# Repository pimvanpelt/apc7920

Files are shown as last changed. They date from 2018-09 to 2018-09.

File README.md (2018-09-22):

# APC7920 based on ESP32

This is a project that replaces the older and unmaintained microcontroller
units in APC's famous rack PDU, the AP7920.

## Intro to AP7920

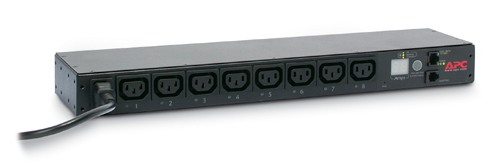
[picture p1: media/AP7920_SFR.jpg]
image of AP7920


The AP7920 is an 8-port switchable rack mounted power distribution unit. It
features three main components:

1.  A power supply board, which has two 24V power supplies (PSU1 and PSU2) and
    three current sensors (Phase A, B and C). Each current sensor measures
    current from 0..30A AC. When sold in Europe, only one of these is used
    (Phase B).
1.  A microcontroller, based on an older Atmel chip, which features serial
    via an RJ12 plug, and 10/100 Ethernet via an RJ45 plug, and a 7-segment
    display which shows load on Phase B.
1.  A relay board, which features a general purpose I2C GPIO expander based on
    PCF8574, and eight 24V relays, one for each port on the front.

The design of this PDU is rather well done, with two power supplies, and a 
decoupled control plane. The wiring is of high quality, even after many
years of service the components are still in pristine shape. Shrink wrap
is used on the wiring for extra safety and the solder quality is very high.

If the microcontroller reboots or fails, the I2C GPIO expander stays put.
This allows operators to upgrade/reboot/tinker-with the management board
without interrupting service to the load.

### Pinouts

#### Power Supply Board

The power supply board has a 10-pin 2mm pitch connector. It exposes the two
24V power supplies, each with their own ground, and the three current sensors,
with their own separate common ground.

The black wire on the ribbon cables is Pin1. 

Pin | Meaning | Pin | Meaning
--- | --- | --- | ---
1 | I-Sens Phase C | 2 | I-Sens GND
3 | I-Sens Phase A | 4 | I-Sens GND
5 | +24V PSU1 | 6 | +24V PSU1
7 | I-Sens Phase B | 8 | GND PSU1
9 | GND PSU2 | 10 | +24V PSU2

It's worth pointing out that on the power supply board, all ground planes
are separated (so there's one ground pin for PSU1, one for PSU2 and one for
the current sensors).

#### Relay Board

The relay board has a 10-pin 2mm pitch connector. It exposes the I2C chip
which takes common `SDA`, `SDL`, `3.3V` and `GND` pins, and exposes three
address pins `ADDR0`, `ADDR1`, and `ADDR2`. This is presumably done so that
the microcontroller can address up to 8 of these relay boards. It also takes
24V in, which is used to drive the relays.

Pin | Meaning | Pin | Meaning
--- | --- | --- | ---
1 | GND | 2 | GND
3 | VDD (3.3V) | 4 | SDA
5 | +24V | 6 | +24V
7 | ADDR0 | 8 | SDL
9 | ADDR1 | 10 | ADDR2

AP7920 only has one expander, so it doesn't really matter which address
the MCU selects.

## Interposer board

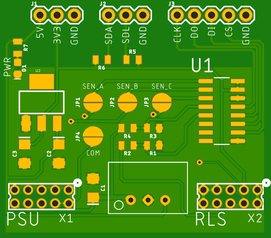
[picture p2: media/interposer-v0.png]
Eagle Interposer


This project works by replacing the two ribbon cables that go from the power
supply board and the relay board to the microcontroller. It's designed to
be a plugin replacement -- just remove the connectors from the microcontroller
and plug them into the interposer board instead.

The interposer has a few components. Firstly, there's a DC/DC buck converter
which takes 24V from PSU1 and switches it down to 5V. Then, there's a LDO that
takes the 5V and regulates it down to 3.3V. Lastly, there's an ADC chip that
measures the current on Phase A,B,C and the voltage out of PSU1 and PSU2 by 
using voltage dividers (the ADC runs at 3.3V so at least a 7:1 divider is
necessary to measure the 24V coming out of the PSUs). The 24V rail from PSU2
is looped through to the relay board. It exposes its 3.3V rail to the relay
board as well, to power the GPIO expander and a few other components there.

It exposes its ADC chip on the SPI header (taking `CS`, `CLK`, `DI` and `DO`)
and it exposes the GPIO expander from the relay board on the I2C header
(showing `SDA`, `SDL`). It offers the 5V and 3.3V rails on the PWR header.
This is enough to connect any other microcontroller that speaks I2C and SPI
instead of the microcontroller that comes with the AP7920 itself. The
interposer assumes only one PCF8574 chip, so it ties all three address pins
`ADDR0`, `ADDR1` and `ADDR2` to `GND`.

The interposer also ties `GND` together from both PSUs, as the original
microcontroller also does that. It has a solder pad (J4) that allows the
current sensor ground to be tied to the main ground as well. In production,
all four solder pads (J1..J4) should be soldered closed. This connects the
current sensor output to the ADC. You can measure the voltage between J4
and J1..J3 to see the current sensed on Phase A..C.

**NOTE** - There is a design flaw in the PCB as it assumes the current
sensor common should be tied to ground, which is not the case. It should be
tied to `VCC/2` so that the signal of the current transformer outputs hovers
between 0-3.3V instead of -1.65-1.65V. A new version is upcoming :)

### BOM

The following components are readily available on Mouser and Digikey. The
full bill of materials for the interposer is as such:

*   R1,R3: 10K Ohm -- voltage divider
*   R2,R4: 75K Ohm -- voltage divider (7:1 minimum)
*   R5,R6: 10K Ohm -- pullup for I2C, optional
*   R7: 220 Ohm -- for blue LED
*   D1: Blue LED 
*   C1: 22uF Tantalum 35V
*   C2,C3: 10uF Tantalum 16V
*   U1: MCP3208 -- 150mil SOIC (Microchip)
*   U2: TSR1-2450 (Traco Power)
*   X1, X2: 5x2 pin 2mm spaced header
*   J1, J2: 3x1 pin 2.54mm spaced header
*   J3: 5x1 pin 2.54mm spaced header

## ESP32 / ESP8266

There are two chips we have to interface with:

*   MCP3208 [datasheet](media/MCP3208.pdf); [driver](https://github.com/mongoose-os-libs/mcp320x-spi)
*   PCF8574 [datasheet](media/PCF8574.pdf); [driver](https://github.com/mongoose-os-libs/pcf8574-i2c)

Libraries for these two chips are readily available for Arduino, but I've
ported them as well to [Mongoose OS](https://mongoose-os.com/) which is my
development platform of choice. This makes writing the program really easy.

### Source Code

See the [firmware](firmware/README.md) directory for information on the firmware.

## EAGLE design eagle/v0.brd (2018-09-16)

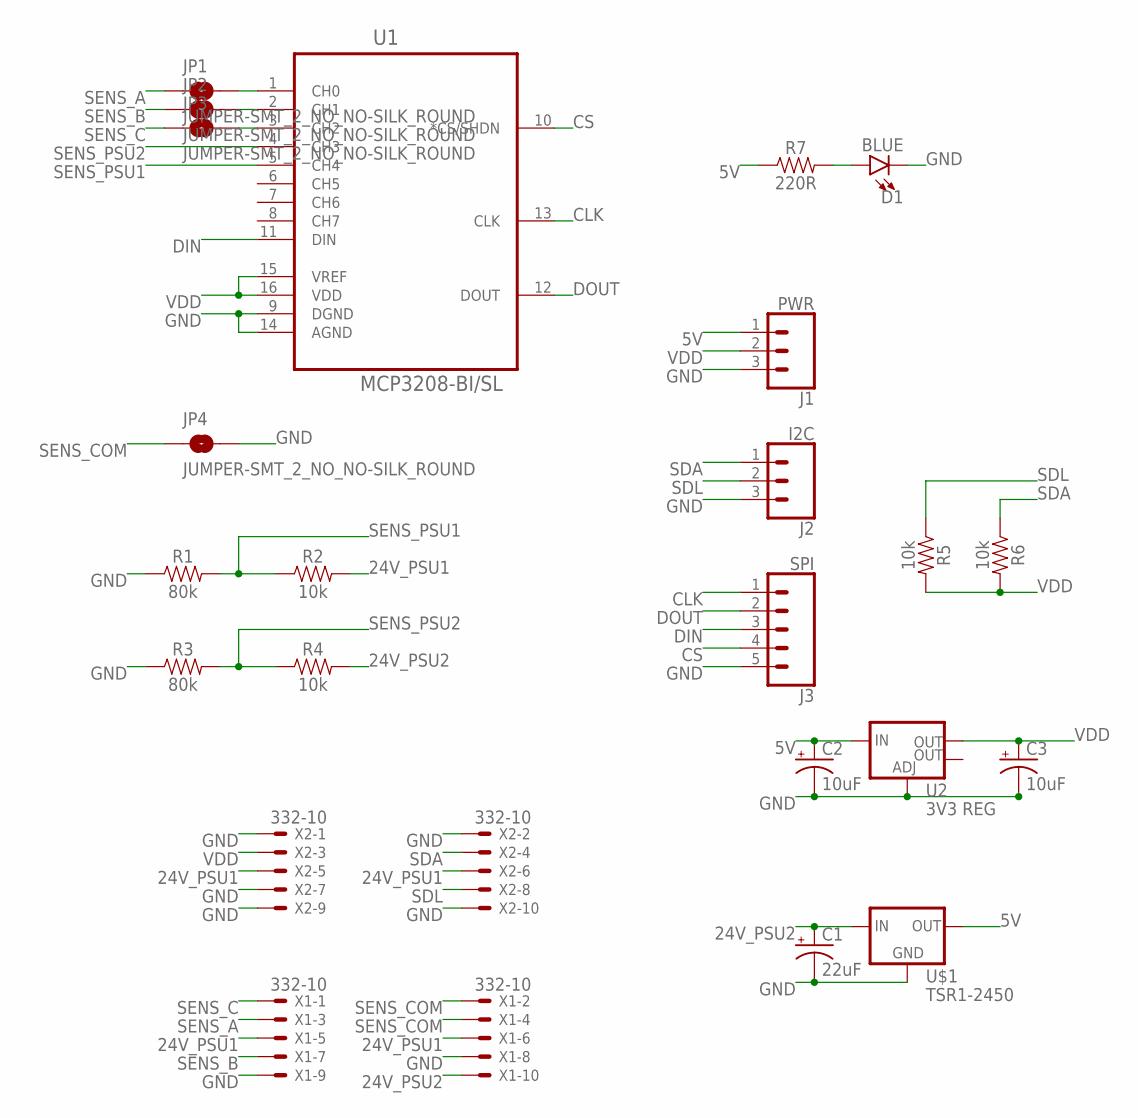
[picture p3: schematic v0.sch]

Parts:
C1: 22uF; EIA3216
C2, C3: 10uF; EIA3216
D1: BLUE; LED-0603
J1: PWR; 1X03
J2: I2C; 1X03
J3: SPI; 1X05
JP1, JP2, JP3, JP4: JUMPER-SMT_2_NO_NO-SILK_ROUND; SMT-JUMPER_2_NO_NO-SILK_ROUND
R1, R3: 80k; 0805
R2, R4, R5, R6: 10k; 0805
R7: 220R; 0805
U1: MCP3208-BI/SL; SOIC127P600X175-16N
U2: 3V3 REG; SOT223
U$1: TSR1-2450
X1, X2: 332-10

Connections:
5V: C2.+, J1.1, R7.1, U2.3 (IN), U$1.3 (OUT)
24V_PSU1: R2.2, X1.5, X1.6, X2.5, X2.6
24V_PSU2: C1.+, R4.2, U$1.1 (IN), X1.10
CLK: J3.1, U1.13 (CLK)
CS: J3.4, U1.10 (*CS/SHDN)
DIN: J3.3, U1.11 (DIN)
DOUT: J3.2, U1.12 (DOUT)
GND: C1.-, C2.-, C3.-, D1.C, J1.3, J2.3, J3.5, JP4.2, R1.1, R3.1, U1.9 (DGND), U1.14 (AGND), U2.1 (ADJ), U$1.2 (GND), X1.8, X1.9, X2.1, X2.2, X2.7, X2.9, X2.10
unnamed: JP1.2, U1.1 (CH0)
unnamed: JP2.2, U1.2 (CH1)
unnamed: JP3.2, U1.3 (CH2)
unnamed: D1.A, R7.2
SDA: J2.1, R6.1, X2.4
SDL: J2.2, R5.1, X2.8
SENS_A: JP1.1, X1.3
SENS_B: JP2.1, X1.7
SENS_C: JP3.1, X1.1
SENS_COM: JP4.1, X1.2, X1.4
SENS_PSU1: R1.2, R2.1, U1.5 (CH4)
SENS_PSU2: R3.2, R4.1, U1.4 (CH3)
VDD: C3.+, J1.2, R5.2, R6.2, U1.15 (VREF), U1.16 (VDD), U2.2 (OUT), X2.3

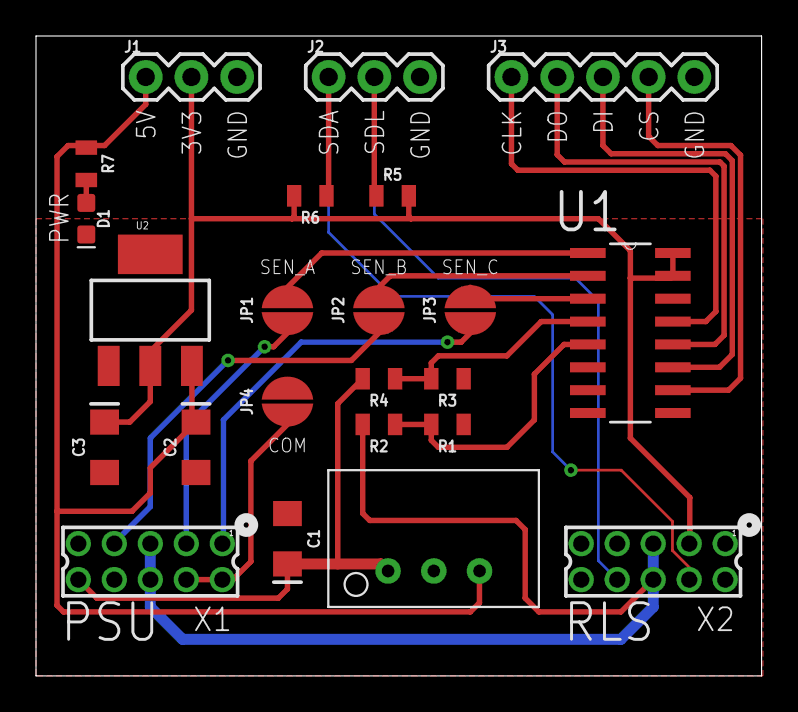
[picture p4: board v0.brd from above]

Board: 2 copper layers, 40.3 x 35.5 mm, 23 parts (0 on the bottom side), 21 nets.

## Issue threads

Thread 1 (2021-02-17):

Sense ground change.

camprr, 2021-02-17:
Pim,

interested in looking at this as I have a broken apc7920. Did you manage to make the modification needed to the PCB to sense the voltage correctly as you state in the Readme? Thanks for _any_ response.

Robert

pimvanpelt, 2021-02-17:
Hoi Robert, thanks for reaching out. The interposer board posted does work
but I did not pursue the project further. It turns out the ESP32 ADC cannot
sample as fast as I was lead to believe when reading its I2S peripheral
documentation, and then the project fell by the wayside.

On Wed, Feb 17, 2021 at 9:55 PM Robert Campbell <notifications@github.com>
wrote:

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

--
Pim van Pelt <pim@ipng.nl>
PBVP1-RIPE - http://www.ipng.nl/

camprr, 2021-02-22:
Good to know, thanks for getting back to me on that!
Maybe I'll 'just' make the switching work then. Have a broken 7920 here that I'd like to get working again. Otherwise is would just be a simple 'hotwire' from the jumper to the pin you mention, right?

pimvanpelt, 2021-02-22:
Making the switching part works is trivial - there's an I2C speaking 8574
GPIO expander on the relay board which has all of its pins (address and
clock / data) exposed on the header. This chip speaks 3.3V and drives the
relays.
I wrote a driver for it here:
https://github.com/mongoose-os-libs/pcf857x-i2c

You can connect your I2C master directly to those SDL/SDA pins and tie
ADDR0,ADDR1,ADDR2 to ground (or any other combination), and then switch the
relays by writing a byte to the latch.
All up, the Mongoose OS code should be possible with less than 100 lines of
code this way.

On Mon, Feb 22, 2021 at 10:06 AM Robert Campbell <notifications@github.com>
wrote:

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

--
Pim van Pelt <pim@ipng.nl>
PBVP1-RIPE - http://www.ipng.nl/

DanMan32, 2023-06-29:
I too came across this project, looking for a way to revive an ap7932  which is a 24P 120V 30A managed PDU.
The processor board just failed yesterday which is a board piggybacked to the display/interface board.
I suspect the buck converter on the processor board failed, one of the tiny chips near the capacitors/inductor gets rather hot.
I was hating to have to dispose of the PDU just because of the processor board having failed.  I figured there was some sort of controlling interface to the relay/outlet boards, your information provided a lot of what I would need to be able to control the outlets.
Any idea what the designation of header pins between the processor board and display/interface board might be?

I hope the I2C and address selector lines from the relay boards go directly to the header pins to the processor board, that would make interfacing with the relay boards from a microcontroller SO much easier than having to source those tiny ribbon cable headers.

DanMan32, 2023-06-29:
Since you're using an external ADC, I'm surprised you have issues interfacing with the ESP32 to read the current.
Or was that comment about the ESP32 sample rate being too slow before you added the ADC IC?

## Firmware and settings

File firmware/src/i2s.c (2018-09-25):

#include "mgos.h"
#include "mgos_config.h"
#include "mgos_prometheus_metrics.h"
#include "driver/i2s.h"
#include "soc/syscon_reg.h"
#include "esp_event_loop.h"
#include "driver/adc.h"

#define SAMPLE_RATE     (9000)
#define I2S_NUM         (0)
#define RINGBUF_SIZE    (16)

struct i2s_scanner_adc_channel {
  uint32_t sum;
  uint16_t count;
  uint16_t min;
  uint16_t max;
};

struct i2s_scanner_adc_channel_set {
  struct i2s_scanner_adc_channel chan[8];
};

struct i2s_scanner_adc_channel_ringbuf {
  struct i2s_scanner_adc_channel_set channel_set[RINGBUF_SIZE];
  uint8_t                            head;
};

struct i2s_scanner_stats {
  uint32_t read_usecs;
  uint32_t read_bytes;
  uint32_t read_count;
};

static QueueHandle_t s_i2s_event_queue;

static struct i2s_scanner_stats s_stats;
static struct i2s_scanner_adc_channel_ringbuf s_ringbuf;
static struct mg_connection *s_udp_nc = NULL;

static void prometheus_metrics_fn(struct mg_connection *nc, void *user_data) {
  struct i2s_scanner_adc_channel_set *channel_set = &s_ringbuf.channel_set[s_ringbuf.head];

  mgos_prometheus_metrics_printf(nc, COUNTER, "i2s_scanner_read_count", "Total samples from I2S",
                                 "%u", s_stats.read_count);
  mgos_prometheus_metrics_printf(nc, COUNTER, "i2s_scanner_read_bytes_total", "Total bytes from I2S",
                                 "%u", s_stats.read_bytes);
  mgos_prometheus_metrics_printf(nc, COUNTER, "i2s_scanner_read_usecs_total", "Total time spent in I2S in microseconds",
                                 "%u", s_stats.read_usecs);

  for (int i = 0; i < 8; i++) {
    mgos_prometheus_metrics_printf(nc, GAUGE, "i2s_scanner_raw", "Raw data from I2S Scanner",
                                   "{channel=\"%u\", type=\"min\"} %u", i,
                                   channel_set->chan[i].min);
    mgos_prometheus_metrics_printf(nc, GAUGE, "i2s_scanner_raw", "Raw data from I2S Scanner",
                                   "{channel=\"%u\", type=\"max\"} %u", i,
                                   channel_set->chan[i].max);
    mgos_prometheus_metrics_printf(nc, GAUGE, "i2s_scanner_raw", "Raw data from I2S Scanner",
                                   "{channel=\"%u\", type=\"avg\"} %f", i,
                                   ((float)channel_set->chan[i].sum) / channel_set->chan[i].count);
  }
  (void)user_data;
}

static void ev_handler(struct mg_connection *nc, int ev, void *ev_data, void *user_data) {
  switch (ev) {
  case MG_EV_RECV: {
//      int bytes_recv = *((int *)ev_data);
//      LOG(LL_INFO, ("Received %d bytes of data on UDP socket", bytes_recv));
    nc->recv_mbuf.len = 0;
    break;
  }

  case MG_EV_SEND: {
//      int bytes_sent = *((int *)ev_data);
//      LOG(LL_INFO, ("Sent %d bytes of data on UDP socket", bytes_sent));
    break;
  }

  default:
    break;
  }
  (void)user_data;
}

static void i2s_scanner_stats(void *args) {
  struct i2s_scanner_adc_channel_set *channel_set = &s_ringbuf.channel_set[s_ringbuf.head];

  for (int i = 0; i < 8; i++) {
    LOG(LL_INFO, ("chan: %d min: %4u max: %4u avg=%.f count=%u",
                  i, channel_set->chan[i].min,
                  channel_set->chan[i].max,
                  ((float)channel_set->chan[i].sum) / channel_set->chan[i].count,
                  channel_set->chan[i].count));
  }
  LOG(LL_INFO, ("stats: bytes=%u count=%u usecs=%u",
                s_stats.read_bytes,
                s_stats.read_count,
                s_stats.read_usecs));

  (void)args;
}

/* This scanner takes approximately 350us to complete, and runs at
 * approx 5Hz allowing us to sample the ADC about 50KHz
 */
static void i2s_scanner(void *pvParams) {
  int            i2s_read_len = 1024 * 2;
  uint16_t       i2s_read_buff[1024];
  system_event_t evt;
  size_t         bytes_read = 0;
  struct i2s_scanner_adc_channel_set *channel_set = &s_ringbuf.channel_set[s_ringbuf.head];
  double   start = mg_time();
  uint32_t usecs_spent;

  if (xQueueReceive(s_i2s_event_queue, &evt, 0) != pdPASS) {
    LOG(LL_WARN, ("No event to consume - consider reducing i2s_scanner frequency"));
    return;
  }

  if (evt.event_id != 2) {     // Event is not I2S_EVENT_RX_DONE
    LOG(LL_ERROR, ("Event %d received, skipping", evt.event_id));
    return;
  }


  i2s_read(I2S_NUM, (char *)i2s_read_buff, i2s_read_len, &bytes_read, portMAX_DELAY);
  // LOG(LL_INFO, ("Received %u bytes", bytes_read));
  // LOG(LL_INFO, ("Reading into channel_set %d", s_ringbuf.head));
  if (s_stats.read_bytes > UINT_MAX - bytes_read) {
    LOG(LL_WARN, ("s_stats.read_bytes overflow"));
    s_stats.read_bytes = 0;
  } else {
    s_stats.read_bytes += bytes_read;
  }

  if (s_stats.read_count == UINT_MAX) {
    LOG(LL_WARN, ("s_stats.read_count overflow"));
    s_stats.read_count = 0;
  } else {
    s_stats.read_count++;
  }

  memset(channel_set->chan, 0, sizeof(struct i2s_scanner_adc_channel) * 8);
  for (int i = 0; i < 8; i++) {
    channel_set->chan[i].min = 0xfff;
  }
  for (int i = 0; i < bytes_read / 2; i++) {
    uint8_t  chan      = (i2s_read_buff[i] >> 12) & 0x07;
    uint16_t adc_value = i2s_read_buff[i] & 0xfff;
    channel_set->chan[chan].count++;
    channel_set->chan[chan].sum += adc_value;
    if (adc_value < channel_set->chan[chan].min) {
      channel_set->chan[chan].min = adc_value;
    }
    if (adc_value > channel_set->chan[chan].max) {
      channel_set->chan[chan].max = adc_value;
    }
  }
  s_ringbuf.head++;
  s_ringbuf.head %= RINGBUF_SIZE;

  if (s_udp_nc) {
    mg_send(s_udp_nc, (void *)i2s_read_buff, bytes_read);
  }

  usecs_spent = 1000000 * (mg_time() - start);
  if (s_stats.read_usecs > UINT_MAX - usecs_spent) {
    LOG(LL_WARN, ("s_stats.read_usecs overflow"));
    s_stats.read_usecs = 0;
  } else {
    s_stats.read_usecs += usecs_spent;
  }
}
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

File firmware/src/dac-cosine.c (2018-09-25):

/* DAC Cosine Generator Example
 *
 * This example code is in the Public Domain (or CC0 licensed, at your option.)
 *
 * Unless required by applicable law or agreed to in writing, this
 * software is distributed on an "AS IS" BASIS, WITHOUT WARRANTIES OR
 * CONDITIONS OF ANY KIND, either express or implied.
 */
#include <stdio.h>
#include <string.h>
#include <stdlib.h>
#include "freertos/FreeRTOS.h"
#include "freertos/task.h"
#include "freertos/queue.h"

#include "soc/rtc_io_reg.h"
#include "soc/rtc_cntl_reg.h"
#include "soc/sens_reg.h"
#include "soc/rtc.h"


#include "driver/dac.h"

#include "mgos.h"

/* Declare global sine waveform parameters
 * so they may be then accessed and changed from debugger
 * over an JTAG interface
 */
int clk_8m_div     = 7; // RTC 8M clock divider (division is by clk_8m_div+1, i.e. 0 means 8MHz frequency)
int frequency_step = 4; // Frequency step for CW generator
int scale          = 2; // 50% of the full scale
int offset         = 0; // leave it default / 0 = no any offset
int invert         = 1; // 2         // invert MSB to get sine waveform


/*
 * Enable cosine waveform generator on a DAC channel
 */
void dac_cosine_enable(dac_channel_t channel) {
  // Enable tone generator common to both channels
  SET_PERI_REG_MASK(SENS_SAR_DAC_CTRL1_REG, SENS_SW_TONE_EN);
  switch (channel) {
  case DAC_CHANNEL_1:
    // Enable / connect tone tone generator on / to this channel
    SET_PERI_REG_MASK(SENS_SAR_DAC_CTRL2_REG, SENS_DAC_CW_EN1_M);
    // Invert MSB, otherwise part of waveform will have inverted
    SET_PERI_REG_BITS(SENS_SAR_DAC_CTRL2_REG, SENS_DAC_INV1, 2, SENS_DAC_INV1_S);
    break;

  case DAC_CHANNEL_2:
    SET_PERI_REG_MASK(SENS_SAR_DAC_CTRL2_REG, SENS_DAC_CW_EN2_M);
    SET_PERI_REG_BITS(SENS_SAR_DAC_CTRL2_REG, SENS_DAC_INV2, 2, SENS_DAC_INV2_S);
    break;

  default:
    LOG(LL_INFO, ("Channel %d\n", channel));
  }
}

/*
 * Set frequency of internal CW generator common to both DAC channels
 *
 * clk_8m_div: 0b000 - 0b111
 * frequency_step: range 0x0001 - 0xFFFF
 *
 */
void dac_frequency_set(int clk_8m_div, int frequency_step) {
  REG_SET_FIELD(RTC_CNTL_CLK_CONF_REG, RTC_CNTL_CK8M_DIV_SEL, clk_8m_div);
  SET_PERI_REG_BITS(SENS_SAR_DAC_CTRL1_REG, SENS_SW_FSTEP, frequency_step, SENS_SW_FSTEP_S);
}

/*
 * Scale output of a DAC channel using two bit pattern:
 *
 * - 00: no scale
 * - 01: scale to 1/2
 * - 10: scale to 1/4
 * - 11: scale to 1/8
 *
 */
void dac_scale_set(dac_channel_t channel, int scale) {
  switch (channel) {
  case DAC_CHANNEL_1:
    SET_PERI_REG_BITS(SENS_SAR_DAC_CTRL2_REG, SENS_DAC_SCALE1, scale, SENS_DAC_SCALE1_S);
    break;

  case DAC_CHANNEL_2:
    SET_PERI_REG_BITS(SENS_SAR_DAC_CTRL2_REG, SENS_DAC_SCALE2, scale, SENS_DAC_SCALE2_S);
    break;

  default:
    LOG(LL_INFO, ("Channel %d\n", channel));
  }
}

/*
 * Offset output of a DAC channel
 *
 * Range 0x00 - 0xFF
 *
 */
void dac_offset_set(dac_channel_t channel, int offset) {
  switch (channel) {
  case DAC_CHANNEL_1:
    SET_PERI_REG_BITS(SENS_SAR_DAC_CTRL2_REG, SENS_DAC_DC1, offset, SENS_DAC_DC1_S);
    break;

  case DAC_CHANNEL_2:
    SET_PERI_REG_BITS(SENS_SAR_DAC_CTRL2_REG, SENS_DAC_DC2, offset, SENS_DAC_DC2_S);
    break;

  default:
    LOG(LL_INFO, ("Channel %d\n", channel));
  }
}

/*
 * Invert output pattern of a DAC channel
 *
 * - 00: does not invert any bits,
 * - 01: inverts all bits,
 * - 10: inverts MSB,
 * - 11: inverts all bits except for MSB
 *
 */
void dac_invert_set(dac_channel_t channel, int invert) {
  switch (channel) {
  case DAC_CHANNEL_1:
    SET_PERI_REG_BITS(SENS_SAR_DAC_CTRL2_REG, SENS_DAC_INV1, invert, SENS_DAC_INV1_S);
    break;

  case DAC_CHANNEL_2:
    SET_PERI_REG_BITS(SENS_SAR_DAC_CTRL2_REG, SENS_DAC_INV2, invert, SENS_DAC_INV2_S);
    break;

  default:
    LOG(LL_INFO, ("Channel %d\n", channel));
  }
}

static void dac_cb(void *arg) {
  // frequency setting is common to both channels
  dac_frequency_set(clk_8m_div, frequency_step);

  /* Tune parameters of channel 2 only
   * to see and compare changes against channel 1
   */
  dac_scale_set(DAC_CHANNEL_2, scale);
  dac_offset_set(DAC_CHANNEL_2, offset);
  offset += 8;
  if (offset > 255) {
    offset = 0;
  }
  dac_invert_set(DAC_CHANNEL_2, invert);

  float frequency = RTC_FAST_CLK_FREQ_APPROX / (1 + clk_8m_div) * (float)frequency_step / 65536;
  LOG(LL_INFO, ("clk_8m_div: %d, frequency step: %d, frequency: %.0f Hz", clk_8m_div, frequency_step, frequency));
  LOG(LL_INFO, ("DAC2 scale: %d, offset %d, invert: %d", scale, offset, invert));
}

/*
 * Generate a sine waveform on both DAC channels:
 *
 * DAC_CHANNEL_1 - GPIO25
 * DAC_CHANNEL_2 - GPIO26
 *
 * Connect scope to both GPIO25 and GPIO26
 * to observe the waveform changes
 * in response to the parameter change
 */
void dac_cosine_init() {
  dac_cosine_enable(DAC_CHANNEL_1);
  dac_cosine_enable(DAC_CHANNEL_2);

  dac_output_enable(DAC_CHANNEL_1);
  dac_output_enable(DAC_CHANNEL_2);

  mgos_set_timer(2000, true, dac_cb, NULL);
}

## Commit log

2018-09-16 Add v0 of the PCB
    [v0.brd, v0.sch]
2018-09-16 Add vendors to BOM -- add Traco buck converter
2018-09-16 Add datasheets; Allude to drivers (to be written)
2018-09-16 Empty firmware skeleton for ESP32
2018-09-16 Add more skeleton
    - add MCP320X driver -- to be published upstream
    - add PCF8574 driver -- to be published upstream
    - add ADC stubs and adc_init();
    - remove SPI/I2C from main mos.yml -- they will be pulled in by the
    drivers
2018-09-21 New monitor all 8 ADC channels! Grab some stats per channel per measurement cycle
2018-09-21 Remove ESP8266 from build targets, we are using I2S and CW generator, specific to ESP32
2018-09-21 Add some stats counters to i2c_scanner (to be exported by Prometheus)
2018-09-21 Add ringbuffer of size 16; Move stats printing to a 5s timer, so it's less chatty
2018-09-21 Run i2c_scanner at idle priority and add runtime info in a note
2018-09-22 Add UDP mirror for I2S samples
2018-09-22 Allow Channel.Get to be called w/o args, in which case we return all channels
2018-09-22 Update README with a note on the CT ADC interaction
2018-09-25 Rewrite DAC task to mgos timer
2018-09-25 Clean up headers that are no longer needed.
    [i2s.c]
2018-09-25 Reduce timer to 5Hz, so we ~always have an event ready to consume

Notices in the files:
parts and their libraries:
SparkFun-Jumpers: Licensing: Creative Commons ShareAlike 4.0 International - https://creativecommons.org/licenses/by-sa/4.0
